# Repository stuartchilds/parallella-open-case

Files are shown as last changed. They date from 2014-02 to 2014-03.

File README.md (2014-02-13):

# Parallella Open Case

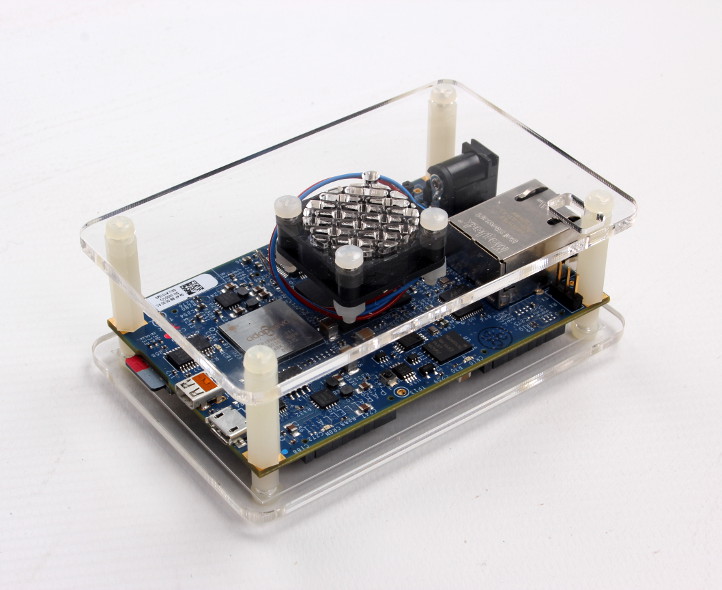
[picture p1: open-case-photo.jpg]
Parallella open case


A simple open case for the Gen1 [Parallella](http://www.parallella.org/) computer.

The design is available in the following formats:

* Corel Draw (source)
* SVG
* PNG
* PDF
* DXF

Note that the Parallella logo has been added to the lid since the above photo was taken.

## Material and cutting

Designed to be laser cut from 3mm clear acrylic. 

## Cooling 

An [EBM PAPST 255H](http://www.ebmpapst.com/en/products/compact-fans/axial-compact-fans/axial_compact_fans_detail.php?pID=53708) fan was originally used, but this is quite possibly overkill and one of the lower air flow (and quieter!) variants of the model 255 may suffice. Alternatively, another 5vdc fan of similar proportions and with mounting holes spaced 20mm apart could be used.

It is possible that washers will need to be inserted between the fan and acrylic in order to prevent the blade from catching.

J15 on the Parallella will need to be bridged in order to enable 5v to be routed to one of the mounting hole pads, as this is where the fan takes its power from. See the Parallella documentation for details.

Note that a heatsink should still be used with the Zynq chip, however, the one supplied with the Parallella may be too tall if using 20mm hex spacers between the board and the lid.

## Fittings

| Qty | Item |
| --- | --- |
|  4  | M3 12mm nylon screw |
|  4  | M3 20mm nylon hex threaded spacer |
|  4  | 3.2mm ID x 3mm circular nylon spacer|
|  7  | M3 16mm nylon screw |
|  3  | M3 nylon washer |
|  3  | M3 nylon nut |
|  2  | M3 tinned solder tag |

## Licence

Copyright 2014 [AB Open Ltd](http://abopen.com).

<br />This work is licensed under a <a rel="license" href="http://creativecommons.org/licenses/by/4.0/">Creative Commons Attribution 4.0 International License</a>.

## Thanks

With thanks to [Oomlout](http://oomlout.co.uk/) for their help with design and prototyping.

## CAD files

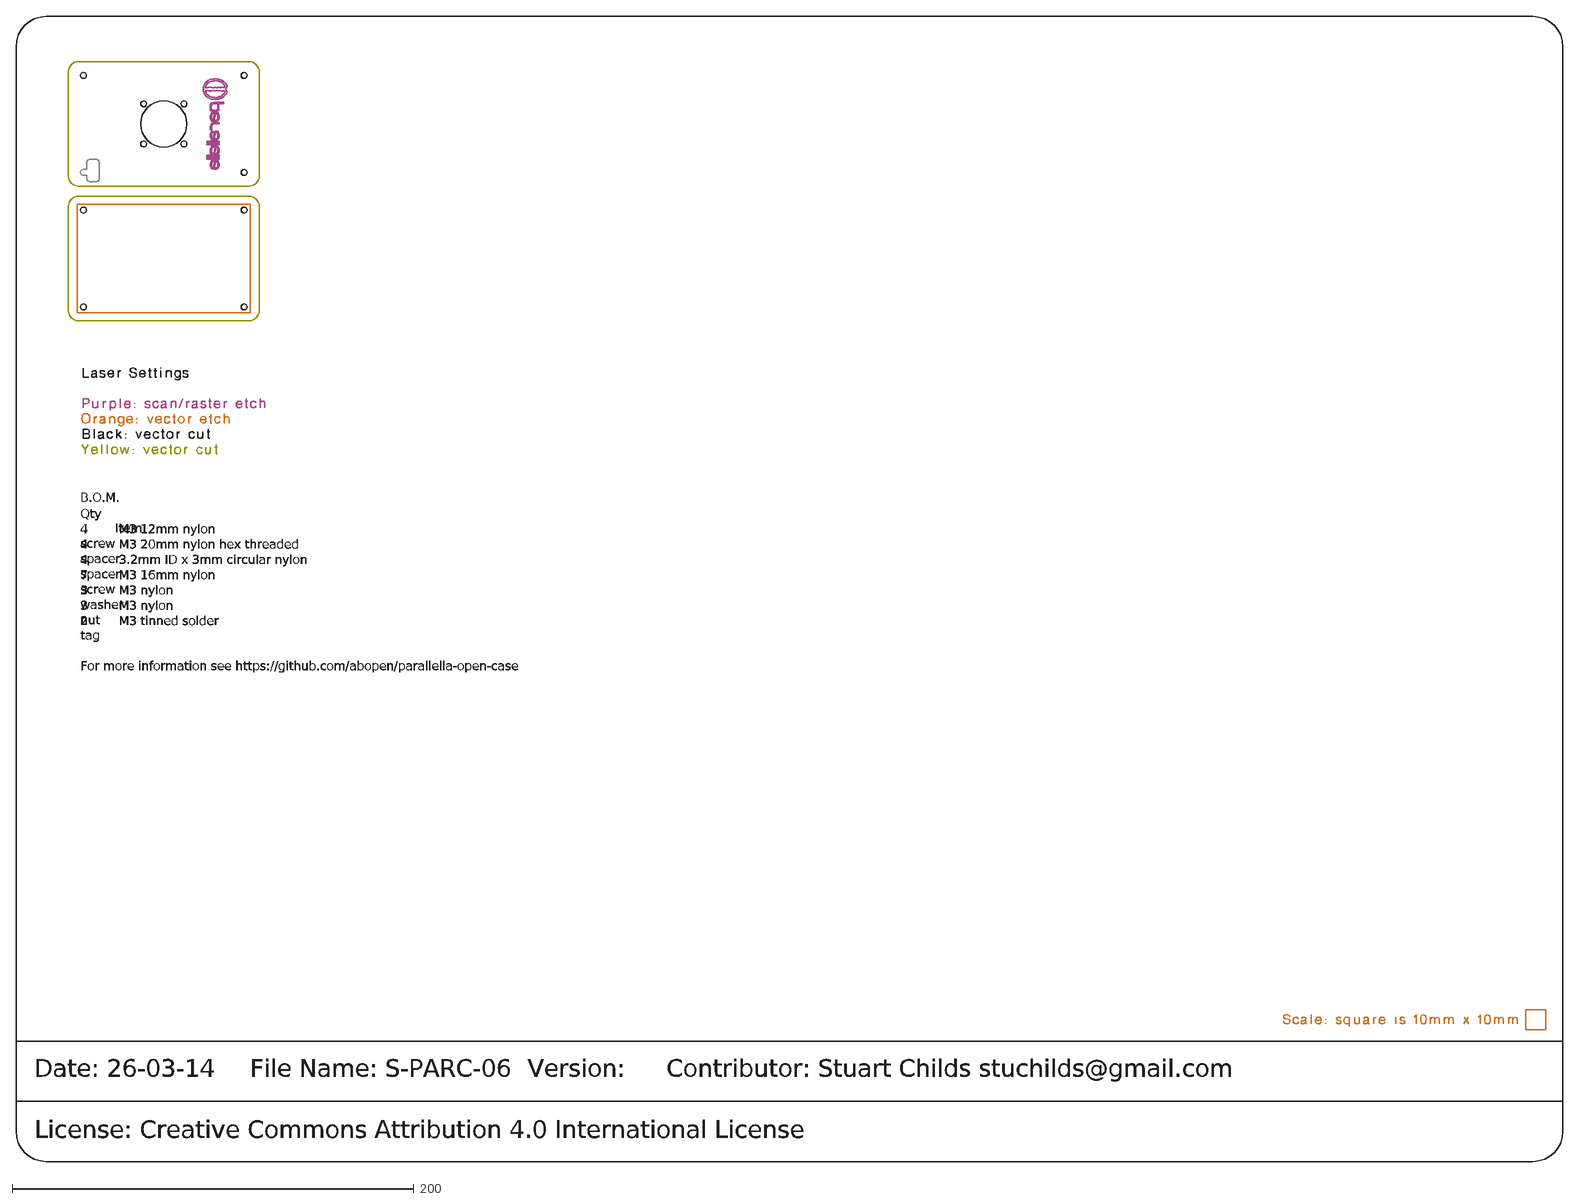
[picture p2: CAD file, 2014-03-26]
PARALLELLA.dxf
Date: 26-03-14 File Name: S-PARC-06 Version: Contributor: Stuart Childs stuchilds@gmail.com
License: Creative Commons Attribution 4.0 International License
B.O.M.
Qty Item
4 M3 12mm nylon screw
4 M3 20mm nylon hex threaded spacer
4 3.2mm ID x 3mm circular nylon spacer
7 M3 16mm nylon screw
3 M3 nylon washer
3 M3 nylon nut
2 M3 tinned solder tag
For more information see https://github.com/abopen/parallella-open-case

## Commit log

2014-02-13 Fixed BOM and added washer note
2014-03-26 Changed design files, added .ai, added design share template
    [PARALLELLA.dxf]

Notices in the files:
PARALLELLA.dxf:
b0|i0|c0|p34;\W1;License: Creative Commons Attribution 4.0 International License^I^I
